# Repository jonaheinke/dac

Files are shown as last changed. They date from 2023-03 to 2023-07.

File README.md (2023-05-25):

# DAC with Headphone Amplifier

## Introduction

## Schematic preview

### Main schematic

main schematic

### Left amplifier (right channel is identical)

left amplifier

### Power supply

power supply

### Front plate

power supply

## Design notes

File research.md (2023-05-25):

TIs Opamps
OPA165x great, probably better
OPA1611 recommended 
https://www.diyaudio.com/community/threads/choosing-of-best-sounding-op-amps-for-the-lowest-possible-thd-n-really-the-best-way.367692/
https://www.ti.com/de-de/amplifier-circuit/op-amps/audio/products.html

https://youtu.be/7irqcglKvKk

https://www.ampslab.com/c300.htm

https://electronics.stackexchange.com/questions/602517/discrete-headphone-amplifier-output-stage

https://www.eevblog.com/forum/projects/who-makes-and-where-to-buy-usb-audio-chips/

https://de.wikipedia.org/wiki/I%C2%B2S
Unbedingt den PCM2706C oder PCM2707C (auf DigiKey nicht verfügbar) von TI nehmen (C ist wichtig, PJT folgt immer, ob R(eel) oder nicht ist egal)
Die anderen (insbesondere PCM290x) haben kein I²S
Unterschied zwischen C und nicht C Chips: https://www.ti.com/lit/an/sbfa019/sbfa019.pdf

andere chips: CM6635 (mouser, wie im schiit hel), CP2615 (24bit 48k discontinued), CS8412, CS8416 (mouser)
Gibt es Alternativen von Cirrus Logic?
http://3.bp.blogspot.com/-GhfnEOvmYFY/UG3X19q91BI/AAAAAAAAAgU/z2ZkhkYbzWM/s1600/i2s_interface.jpg

dac chips:
- PCM1753
- PCM1754
- PCM1755
- PCM1780
- PCM1781
- PCM1782
- CS4344

https://www.headphonesty.com/headphone-power-calculator/

@120dB:
max power: Audeze LCD-3 - 1315mWrms
max voltage: Beyerdynamic DT770 PRO - 12.59Vrms
max current: Audeze LCD-3 - 165.5mArms

@110dB:
max power: Audeze LCD-3 - 132mWrms
max voltage: Beyerdynamic DT770 PRO - 4Vrms
max current: Audeze LCD-3 - 52.4mArms

overcurrent chip:
https://www.digikey.de/de/products/detail/richtek-usa-inc/RT1720GF/6002895
overcurrent circuit: https://forum.allaboutcircuits.com/threads/current-limiting-circuit.170070/  https://electronics.stackexchange.com/questions/200716/current-limiting-with-mosfet

https://hackaday.com/2013/08/27/building-a-high-end-usb-audio-dac/

helpful: caps should be tht (especially dc blocking -> film), for resistors it doesn't matter (except output emitters)
	https://www.youtube.com/watch?v=4ZUBda5oIUo
not so helpful: https://www.youtube.com/watch?v=iJazCWnAmkM

helpful: for dc blocking and even power: use good film cap with large electrolytic in parallel (do they have to be dual polarity for dc block???)
	(0.1-0.2uF for power rails| could this be biased, because no lower value cap was paralleled beforehand?)
	https://www.youtube.com/watch?v=mCk50RTtrT0
	https://www.youtube.com/watch?v=FQOWd-mObFQ

helpful: eevblog multiple caps (especially results at 80% time, multiple can make it worse, check bode plots for all (power) caps)
	https://www.youtube.com/watch?v=BcJ6UdDx1vg

Switchmode? https://www.youtube.com/watch?v=p0fJSaVljeg

good precision current source: https://sound-au.com/ism.htm

TO WATCH/READ:
- https://www.youtube.com/watch?v=PkJqE-EsoWY
- how to design front panels: https://www.youtube.com/watch?v=wg_J9WElvBY

TO BUY:
- case: Hammond 1455N1601BK (02 variant has no separate face plate)
- USB C extender
- isolation heat pads !!!!!!!!!!!!!!!!!! (and check heat sink footprint)
- nylon isolators for screws
- gold screws for panels -> see https://www.youtube.com/watch?v=wg_J9WElvBY @ 5:05
- screw size for 1455N1602BK
  - original: 1455MS100
  - screw length: 9.5mm == 0.375" == 15/32"
  - screw diameter: M3.5 == 3.5mm == 0.138" == 9/64" == #6
  - thread per inch: 32 (e.g #6-32)
- USB to I²S chips
- audio dacs
- output resistors
- output transistors
- vas transistors
- input transistors
- 0 ohm smd resistors
- collection of different smd resistors
- power caps
- film caps for dc blocking and power supply
- ceramic caps (smd?? closest to output transistors, miller compensation)
- button with rgb light for power button and status
- transformer
- FUUULLL BRIDGE RECTIFIAAA!
- power jack

Transformer: 

Mains input: https://www.digikey.de/de/products/detail/delta-electronics/06A2/3830616

USB extender: https://de.aliexpress.com/item/1005003747287943.html oder https://de.aliexpress.com/item/1005003439708042.html

USB breakout: https://www.digikey.de/de/products/detail/sparkfun-electronics/BOB-15100/9770720

function generator: https://www.youtube.com/watch?v=Y1KE8eAC9Bk @ 4:40

use resettable fuse for power supply

diode gates: https://www.sanfoundry.com/analog-electronic-circuits-questions-answers-diode-gates-rectifiers/

https://de.aliexpress.com/item/1005003917089451.html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

https://www.digikey.de/de/products/detail/adafruit-industries-llc/5531/16653412

for silkscreen images: see https://www.youtube.com/watch?v=hoLf8gvvXXU for min line thickness

# other dacs

## schiit LYR

https://www.schiit.com/products/lyr

- has good description of power supply

Gain: 5.7 (15dB) on high, 1.2 (1.35dB) on low

(per channel)
23 Vpeak, 39mApeak @ 600Ω, 450mW
17 Vpeak, 1Apeak @ 16Ω, 9W

## QRV01

https://sjostromaudio.com/pages/index.php/hifi-projects/122-qrv01-headphone-amp
ay yo wtf

- https://jlcpcb.com/help/article/16-How-to-generate-Gerber-and-Drill-files-in-KiCad-6

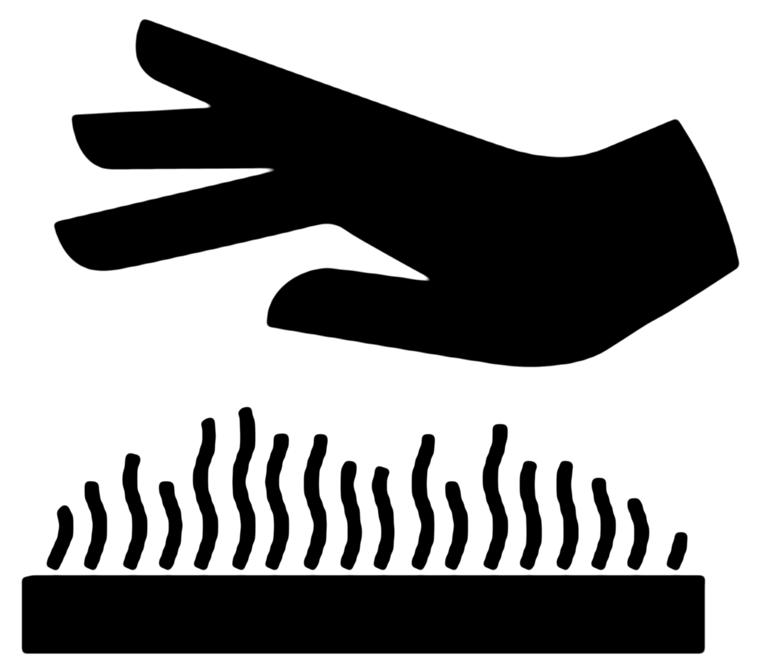
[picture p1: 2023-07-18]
kicad/images/heat-warning.png

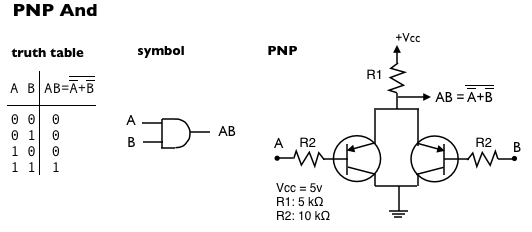
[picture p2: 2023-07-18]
kicad/images/PNP-And.png

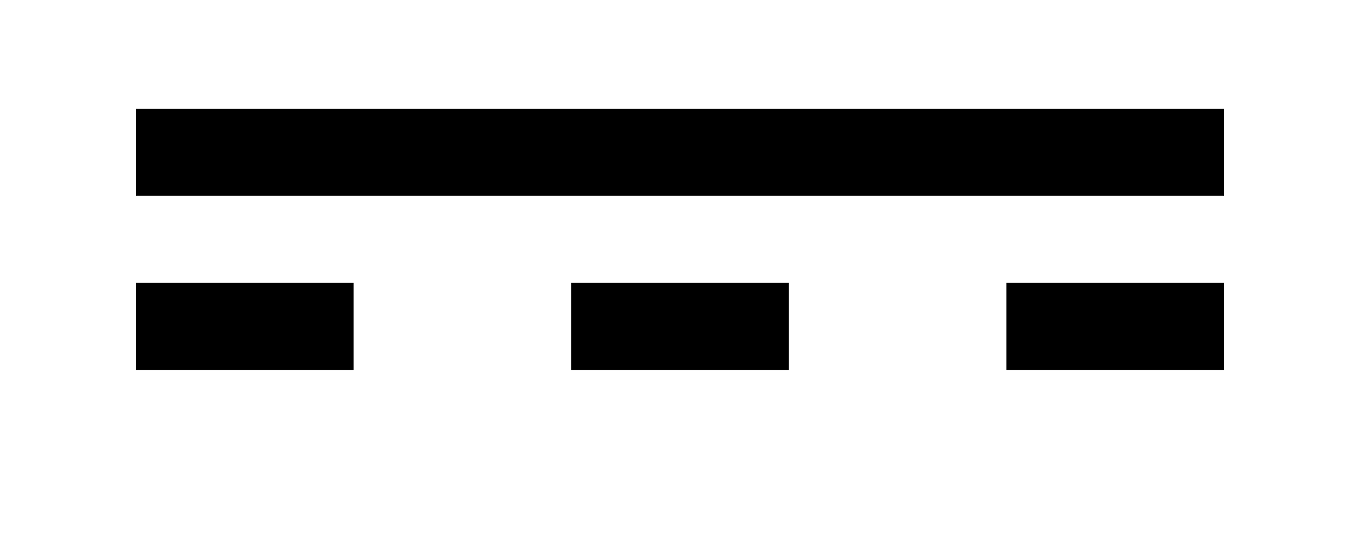
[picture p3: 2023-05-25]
kicad/images/2560px-Direct_current_symbol.svg.png

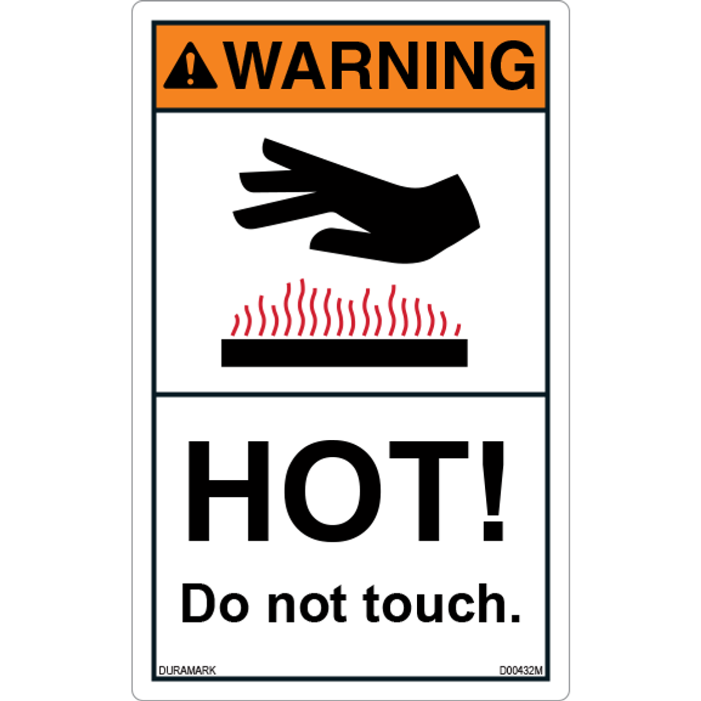
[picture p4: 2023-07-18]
kicad/images/D00432__43247.png

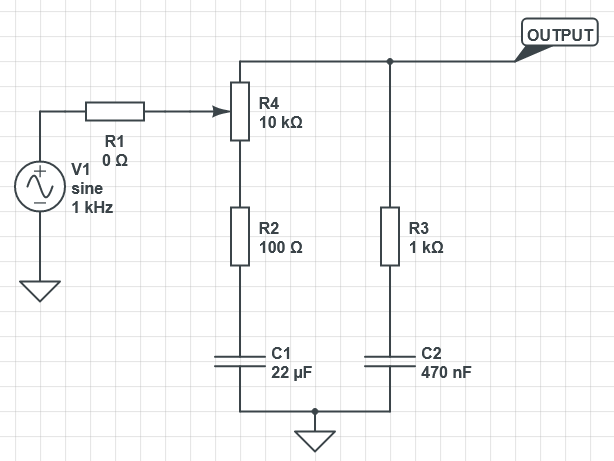
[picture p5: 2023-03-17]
spice/loudness_control_v0.png

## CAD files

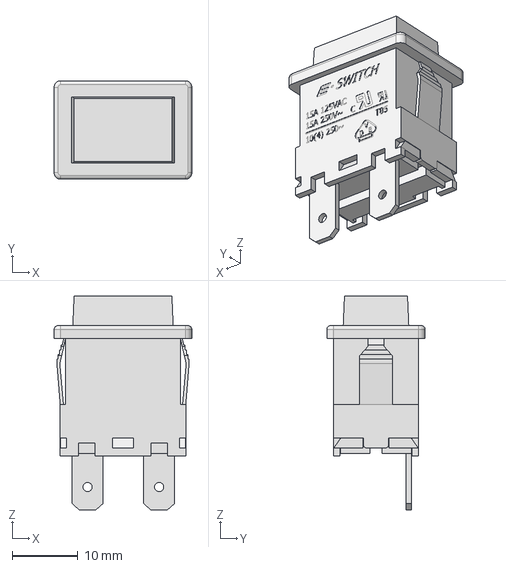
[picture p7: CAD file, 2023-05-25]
kicad/3D/PB1973AxxxxxxEF0.stp
21.0 x 15.0 x 32.6 mm

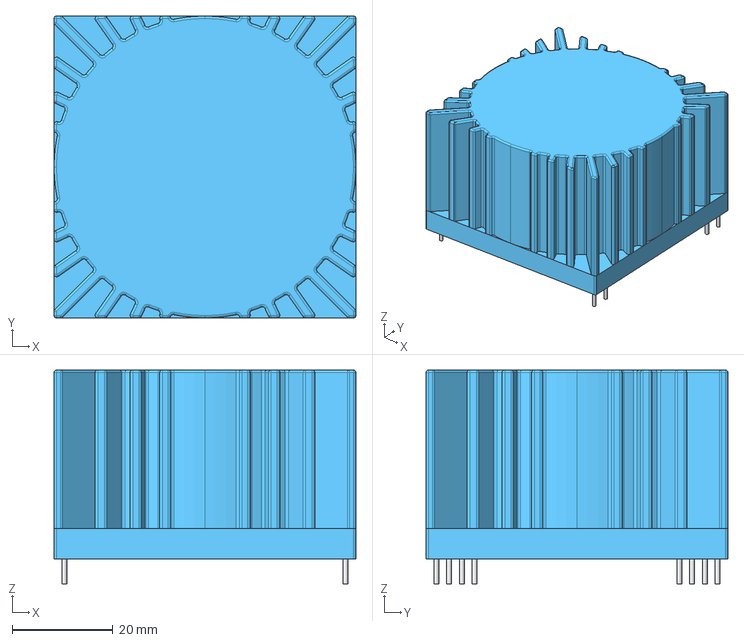
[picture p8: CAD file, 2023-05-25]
kicad/3D/TALEMA_25VA_7006X.step
60.0 x 60.0 x 42.5 mm

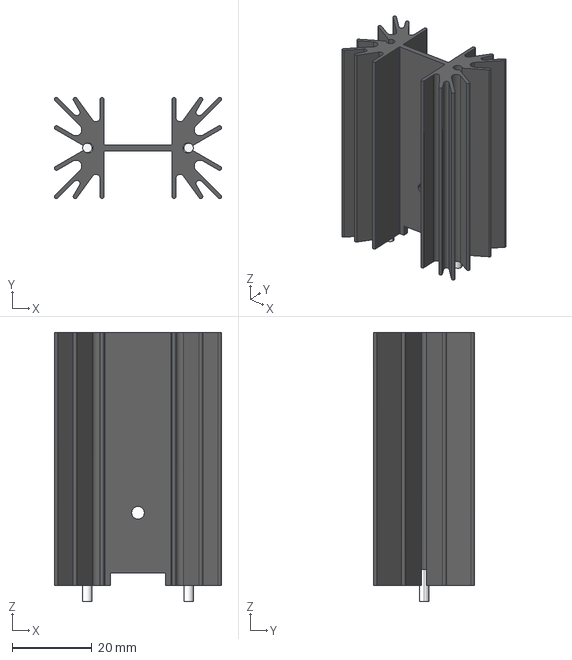
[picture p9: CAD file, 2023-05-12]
kicad/3D/TO-220_Heatsink.stp
41.9 x 25.4 x 67.5 mm

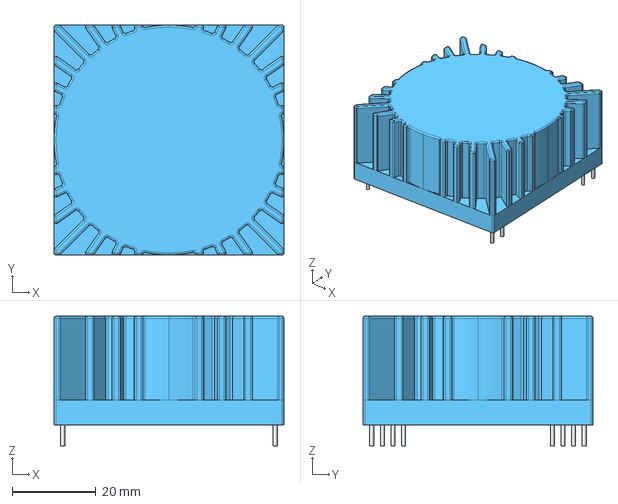
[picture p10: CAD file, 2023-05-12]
kicad/3D/TALEMA_10VA_7004X.step
55.0 x 55.0 x 31.0 mm

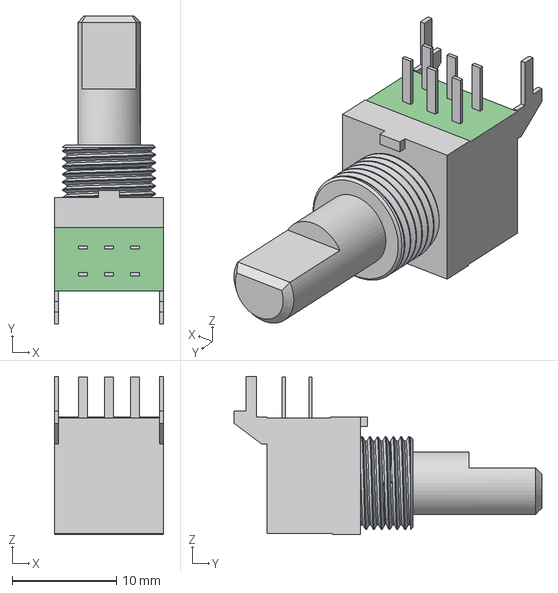
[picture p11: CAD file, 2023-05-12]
kicad/3D/ALPS_RK09L.step
10.5 x 29.6 x 15.2 mm

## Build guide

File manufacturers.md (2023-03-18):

# JLCPCB

- 5pcs 10x10cm 2-layer PCBs for 1,88€ + 3,47€ shipping
- 10pcs 10x10cm 2-layer PCBs for 4,70€ + 7,44€ shipping
- 5pcs 15x10cm 2-layer PCBs for 9,30€ + 6,76€ shipping
- 10pcs 15x10cm 2-layer PCBs for 14,85€ + 8,91€ shipping
- all silkscreen colors available without extra charge

- 4 layer 5pcs 10,2x10,2cm for 6,58€ + 3,47€ shipping

# PCBWAY

- 10pcs 10x10cm 5$ + 6,76$ shipping
- 5pcs 15x10cm 34,54$ + 5,99$ shipping
- all silkscreen colors (except purple and mattes) available without extra charge

# ALLPCB

- 5pcs 10x10cm 2-layer PCBs for 2.50€ + 12€ shipping
- 5pcs 15x10cm 2-layer PCBs for 23€ + 15€ shipping
- non-green silkscreen puts you in the same price bracket as 15x10 (includes matte)

# AISLER

- manufactures in germany

# Pcbcart

- 10x10cm 6€ per board

# Eurocircuits, PCB PROTOTYPE

- viel zu teuer

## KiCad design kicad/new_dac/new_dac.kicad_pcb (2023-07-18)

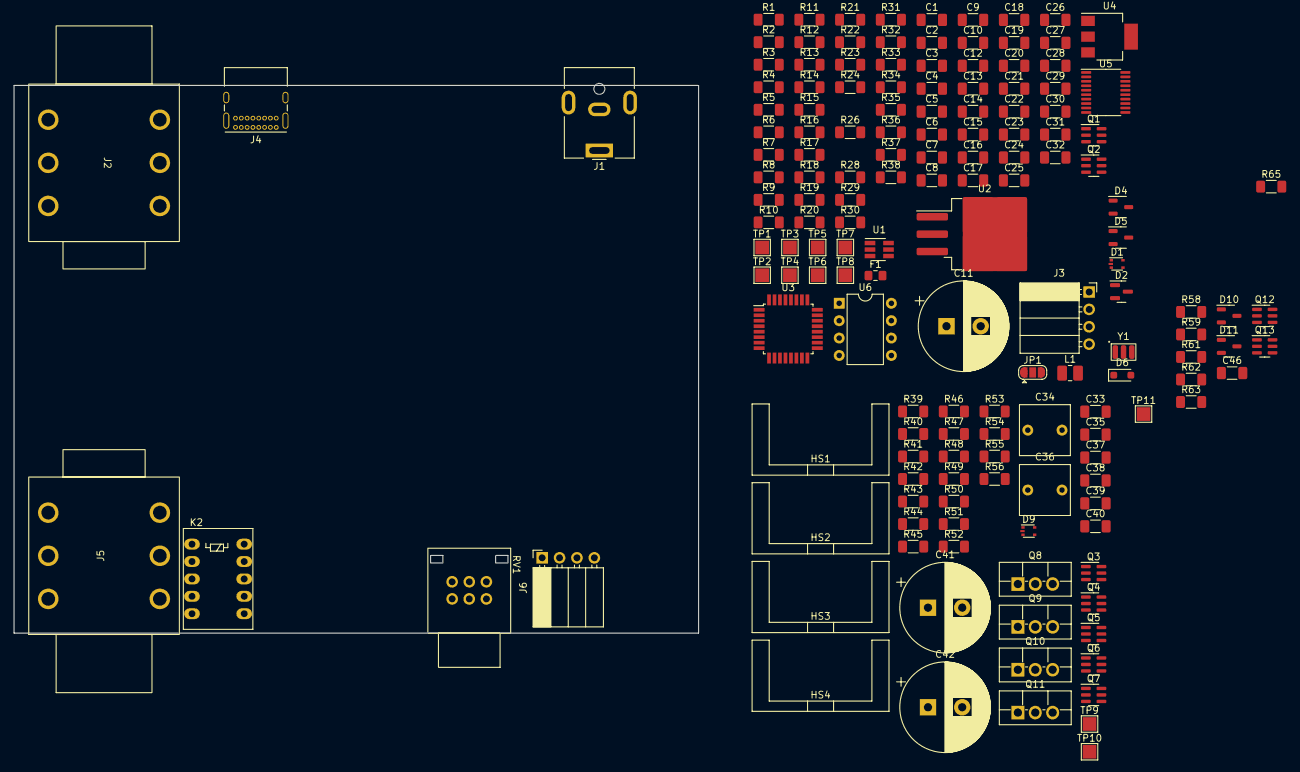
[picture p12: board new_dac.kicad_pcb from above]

Board: 4 copper layers, 100.0 x 80.0 mm, 158 parts (1 on the bottom side), 92 nets, no tracks yet.

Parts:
C1, C7, C9, C10, C14, C15, C18, C21, C32, C37, C38: 100n; C_1206_3216Metric_Pad1.33x1.80mm_HandSolder
C2, C5, C6, C8, C12, C13, C16, C19, C22, C23, C24, C28, C29, C35: 10u; C_1206_3216Metric_Pad1.33x1.80mm_HandSolder
C3, C4, C25, C30, C31: 15n; C_1206_3216Metric_Pad1.33x1.80mm_HandSolder
C11: 470u; CP_Radial_D13.0mm_P5.00mm
C17, C20, C26, C46: 2u2; C_1206_3216Metric_Pad1.33x1.80mm_HandSolder
C27: 1n; C_1206_3216Metric_Pad1.33x1.80mm_HandSolder
C33: 4u7; C_1206_3216Metric_Pad1.33x1.80mm_HandSolder
C34: 4u7; C_Rect_L7.2mm_W7.2mm_P5.00mm_FKS2_FKP2_MKS2_MKP2
C36: 10u; C_Rect_L7.2mm_W7.2mm_P5.00mm_FKS2_FKP2_MKS2_MKP2
C39, C40: 470u; C_1206_3216Metric_Pad1.33x1.80mm_HandSolder
C41, C42: 10u; CP_Radial_D13.0mm_P5.00mm
D1, D9: QUAD_TVS_5V; SOT-665
D2, D7: DUAL_TVS_15V; SOT-23
D4, D5: D; SOT-23-3
D6: D; D_SOD-323_HandSoldering
D10, D11: SOT-23-3
F1: 500mA; Fuse_0805_2012Metric_Pad1.15x1.40mm_HandSolder
HS1, HS2, HS3, HS4: Heatsink; Heatsink_Boyd_507302B00000G
J1: USB_C_Receptacle_USB2.0; BarrelJack_CUI_PJ-063AH_Horizontal
J2: Barrel_Jack_Switch; Audio_Jack_SJ-6307
J3: Conn_01x04; PinSocket_1x04_P2.54mm_Horizontal
J4: USB_C_Receptacle_USB2.0; USB_C_Receptacle_GCT_USB4085
J5: AudioJack3_Switch; Audio_Jack_SJ-6307
J6: AudioJack3_Switch; PinSocket_1x04_P2.54mm_Horizontal
JP1: Ground_Jumper; SolderJumper-3_P1.3mm_Open_RoundedPad1.0x1.5mm
K2: DPDT_Relay; Relay_DPDT_FRT5
L1: 6u8; L_1008_2520Metric_Pad1.43x2.20mm_HandSolder
Q1, Q5, Q6, Q7, Q12: BCM56DS; SC-74-6_1.5x2.9mm_P0.95mm
Q2, Q3, Q4, Q13: BCM53DS; SC-74-6_1.5x2.9mm_P0.95mm
Q8, Q9, Q10, Q11: 2SC4511; TO-220F-3_Vertical
R1, R2: 5k1; R_1206_3216Metric_Pad1.30x1.75mm_HandSolder
R3, R7, R30, R39, R41: 1k5; R_1206_3216Metric_Pad1.30x1.75mm_HandSolder
R4, R5: 22; R_1206_3216Metric_Pad1.30x1.75mm_HandSolder
R6, R10: 430k; R_1206_3216Metric_Pad1.30x1.75mm_HandSolder
R8, R9, R32: 1M; R_1206_3216Metric_Pad1.30x1.75mm_HandSolder
R11: 3k9; R_1206_3216Metric_Pad1.30x1.75mm_HandSolder
R12, R24, R31: 680; R_1206_3216Metric_Pad1.30x1.75mm_HandSolder
R13, R16, R19, R22, R33, R34, R37, R38, R43, R45, R55, R56, R61: 22k; R_1206_3216Metric_Pad1.30x1.75mm_HandSolder
R14, R15, R20, R53, R54, R62: 100k; R_1206_3216Metric_Pad1.30x1.75mm_HandSolder
R17, R18, R26, R51, R52: 15; R_1206_3216Metric_Pad1.30x1.75mm_HandSolder
R21, R44, R46, R63: 10k; R_1206_3216Metric_Pad1.30x1.75mm_HandSolder
R23, R47, R48, R65: 2k2; R_1206_3216Metric_Pad1.30x1.75mm_HandSolder
R28, R29, R49, R50: 8R2; R_1206_3216Metric_Pad1.30x1.75mm_HandSolder
R35, R36, R40, R42: 4k3; R_1206_3216Metric_Pad1.30x1.75mm_HandSolder
R58, R59: 47k; R_1206_3216Metric_Pad1.30x1.75mm_HandSolder
RV1: 10k; RK09L12B
TP1: VBUS; TestPoint_Pad_2.0x2.0mm
TP2: +24; TestPoint_Pad_2.0x2.0mm
TP3: +5V; TestPoint_Pad_2.0x2.0mm
TP4: +22; TestPoint_Pad_2.0x2.0mm
TP5: GND; TestPoint_Pad_2.0x2.0mm
TP6, TP11: +3V3; TestPoint_Pad_2.0x2.0mm
TP7: -3V3; TestPoint_Pad_2.0x2.0mm
TP8: 1V8; TestPoint_Pad_2.0x2.0mm
TP9: VAS_L; TestPoint_Pad_2.0x2.0mm
TP10: VAS_R; TestPoint_Pad_2.0x2.0mm
U1: BD9G101G; SOT-23-6_Handsoldering
U2: LT3088; TO-263-3_TabPin2
U3: PCM2706CPJTR; TQFP-32_7x7mm_P0.8mm
U4: TLV1117LV-33; SOT-223-3_TabPin2
U5: PCM5102A; TSSOP-20_4.4x6.5mm_P0.65mm
U6: LM555xN; DIP-8_W7.62mm
Y1: 12MHz±0.05%; Resonator_Murata

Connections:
+3V3: C7.2, C12.1, C13.1, C14.1, C15.1, C16.1, C21.1, C22.1, R3.2, R7.2, TP6.1, TP11.1, U3.10 (TEST), U3.16 (PSEL), U3.21 (VDD), U3.24 (VBUS), U4.2 (VO), U5.1 (CPVDD), U5.8 (AVDD), U5.20 (DVDD)
+5V: C6.1, C10.1, L1.2, R11.1, R23.1, R33.1, TP3.1, U4.3 (VI), U6.4 (R), U6.8 (VCC)
+20Vreg: C5.1, C11.1, Q3.5 (E1), Q4.5 (E1), Q5.3 (C2), Q6.3 (C2), Q8.2 (C), Q10.2 (C), R13.1, R39.1, R41.1, R47.1, R48.1, TP4.1, U2.2 (OUT)
+24V: C2.1, C26.1, C46.1, J3.1, Q2.5 (E1), Q13.4 (E2), R6.1, R16.1, R20.1, R61.1, R62.1, TP2.1, U1.4 (EN), U1.5 (VCC), U2.3 (IN)
/AMP_L: C39.2, R14.1, R17.1
/AMP_R: C40.2, R15.1, R18.1
/AUDIO_OUT_L: D7.2 (A2), J5.T, K2.8, R28.2
/AUDIO_OUT_R: D7.1 (A1), J5.R, K2.3, R29.2
/BCK: U3.19 (FUNC1), U5.13 (BCK)
/BST: C4.1, U1.1 (BST)
/CAPM: C17.2, U5.4 (CAPM)
/CAPP: C17.1, U5.2 (CAPP)
/CONN_D+: D1.4 (A3), J4.A6 (D+), J4.B6 (D+), R3.1, R5.1
/CONN_D-: D1.3 (A2), J4.A7 (D-), J4.B7 (D-), R4.1
/D+: R5.2, U3.23 (D+)
/D-: R4.2, U3.22 (D-)
/DAC_OUT_L: D9.1 (A1), U5.6 (OUTL)
/DAC_OUT_R: D9.4 (A3), U5.7 (OUTR)
/DATA: U3.17 (DOUT), U5.14 (DIN)
/DC_FUSED: D2.2 (A2), F1.2
/DC_LP_L: C23.1, D4.2 (A), R14.2
/DC_LP_R: C24.1, D5.2 (A), R15.2
/DT: R7.1, U3.15 (DT)
/FEEDBACK: C10.2, R11.2, R12.1, U1.3 (FB)
/LDOO: C18.1, C19.1, TP8.1, U5.18 (LDOO)
/LRCK: U3.5 (FUNC0), U5.15 (LRCK)
/PROT_ARC_L: C28.2, R28.1
/PROT_ARC_R: C29.2, R29.1
/RELAY: K2.1, Q2.6 (C1), R65.1
/RLY_IN_L: C28.1, K2.7, R17.2, R19.2
/RLY_IN_R: C29.1, K2.4, R18.2, R22.2
/Reg_Set: C3.1, R10.1, U2.1 (SET)
/SCK: U3.18 (FUNC2), U5.12 (SCK)
/SSPND: J3.2, U3.11 (~SSPND), U5.17 (XSMT)
/SWITCHING: C4.2, L1.1, U1.6 (LX)
/USB_SHIELD: D1.2 (C), J4.S1 (SHIELD), JP1.3 (B)
/VCCP: C9.2, U3.2 (VCCP)
/VCOM: C8.2, U3.32 (VCOM)
/VNEG: C20.1, TP7.1, U5.5 (VNEG)
/XTI: R8.1, U3.12 (XTI), Y1.1
/XTO: R8.2, U3.13 (XTO), Y1.3
/amplifier/AUDIO_IN_L: D9.3 (A2), RV1.1
/amplifier/AUDIO_IN_R: D9.5 (A4), RV1.4
/amplifier/FB_L: Q5.1 (B1), R35.2, R43.2, R44.1
/amplifier/FB_R: Q6.1 (B1), R36.2, R45.2, R46.1
/amplifier/OPS_L: C39.1, Q8.3 (E), Q9.2 (C), R43.1, R51.1
/amplifier/OPS_R: C40.1, Q10.3 (E), Q11.2 (C), R45.1, R52.1
/amplifier/VAS_L: Q3.3 (C2), Q5.2 (B2), Q5.6 (C1), TP9.1
/amplifier/VAS_R: Q4.3 (C2), Q6.2 (B2), Q6.6 (C1), TP10.1
/old_design/DC_LP_L: C41.1, R53.2, R55.1
/old_design/DC_LP_R: C42.1, R54.2, R56.1
/old_design/DC_NEG: D10.1 (A), D11.1 (A), Q13.1 (B1)
/old_design/DC_POS: D10.3 (K), D11.3 (K), Q12.1 (B1)
/old_design/DC_VD_L: D10.2 (common), R55.2, R58.1
/old_design/DC_VD_R: D11.2 (common), R56.2, R59.1
GND: C2.2, C3.2, C5.2, C6.2, C11.2, C12.2, C35.2, C36.2, C37.2, C38.2, D2.1 (A1), D7.3 (common), D9.2 (C), J3.4, J5.S, J5.SN, JP1.1 (A), Q7.4 (E2), Q7.5 (E1), R6.2, R10.2, R12.2, R13.2, R19.1, R22.1, R37.2, R38.2, R40.2, R42.2, R44.2, R46.2, R49.2, R50.2, RV1.3, RV1.6, TP5.1, U1.2 (GND), U4.1 (GND)
GNDD: C1.2, C7.1, C8.1, C9.1, C13.2, C14.2, C15.2, C16.2, C18.2, C19.2, C20.2, C21.2, C22.2, C23.2, C24.2, C25.2, C27.2, C30.2, C32.2, C41.2, C42.2, D1.5 (A4), D6.2 (A), J4.A1 (GND), J4.A12 (GND), J4.B1 (GND), J4.B12 (GND), JP1.2 (C), K2.2, K2.9, K2.10, Q1.4 (E2), Q1.5 (E1), Q12.4 (E2), Q12.5 (E1), Q13.6 (C1), R1.2, R2.2, R9.1, R31.2, R32.2, R34.2, R58.2, R59.2, U3.1 (PGND), U3.9 (FSEL), U3.20 (DGND), U3.25 (ZGND), U3.26 (AGNDL), U3.31 (AGNDR), U5.3 (CPGND), U5.9 (AGND), U5.10 (DEMP), U5.11 (FLT), U5.16 (FMT), U5.19 (DGND), U6.1 (GND), Y1.2
unnamed: C33.1, RV1.2
unnamed: C33.2, R35.1
unnamed: C34.1, RV1.5
unnamed: C34.2, R36.1
unnamed: C37.1, R51.2
unnamed: C38.1, R52.2
unnamed: D4.1 (K), D5.1 (K), Q1.1 (B1)
unnamed: D6.1 (K), R65.2
unnamed: C32.1, R32.1
unnamed: Q1.2 (B2), Q1.6 (C1), R16.2
unnamed: C26.2, Q1.3 (C2), R21.2
unnamed: Q2.1 (B1), R20.2, R21.1
unnamed: Q3.1 (B1), Q3.4 (E2), R39.2
unnamed: Q3.2 (B2), Q3.6 (C1), R37.1
unnamed: Q4.1 (B1), Q4.4 (E2), R41.2
unnamed: Q4.2 (B2), Q4.6 (C1), R38.1
unnamed: C35.1, Q5.5 (E1), R40.1
unnamed: Q5.4 (E2), Q8.1 (B)
unnamed: C36.1, Q6.5 (E1), R42.1
unnamed: Q7.1 (B1), Q9.3 (E), R49.1
unnamed: Q7.6 (C1), Q9.1 (B), R47.2
unnamed: Q6.4 (E2), Q10.1 (B)
unnamed: Q7.3 (C2), Q11.1 (B), R48.2
unnamed: Q7.2 (B2), Q11.3 (E), R50.1
unnamed: Q12.2 (B2), Q12.6 (C1), Q13.5 (E1), R61.2
unnamed: C46.2, Q12.3 (C2), R63.2
unnamed: Q13.2 (B2), R62.2, R63.1
unnamed: C25.1, U6.5 (CV)
unnamed: R23.2, R24.1, U6.7 (DIS)
unnamed: R26.1, U6.3 (Q)
unnamed: C27.1, R24.2, U6.2 (TR), U6.6 (THR)
unnamed: C30.1, R26.2
unnamed: C31.2, R31.1
unnamed: R33.2, R34.1
VBUS: C1.1, D1.1 (A1), J4.A4 (VBUS), J4.A9 (VBUS), J4.B4 (VBUS), J4.B9 (VBUS), R9.2, TP1.1, U3.3 (HOST)

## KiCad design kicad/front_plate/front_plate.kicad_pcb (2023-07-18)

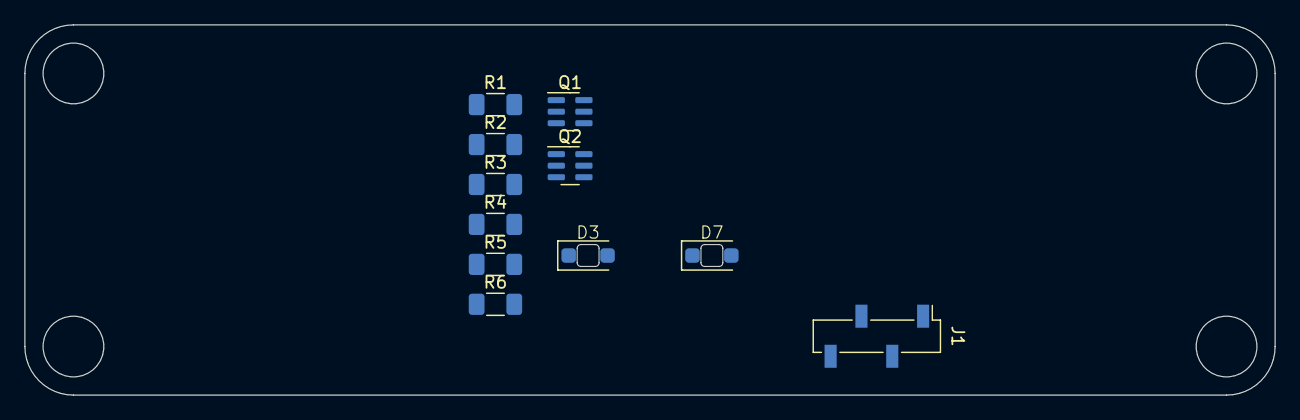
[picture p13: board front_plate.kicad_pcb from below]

Board: 2 copper layers, 103.0 x 30.5 mm, 11 parts (11 on the bottom side), 11 nets, no tracks yet.

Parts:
D3, D7: AMBER; LED_Harvatek_B2601
J1: Conn_01x04; PinSocket_1x04_P2.54mm_Vertical_SMD_Pin1Left
Q1, Q2: BCM56DS; SC-74-6_1.5x2.9mm_P0.95mm
R1: 47k; R_1206_3216Metric_Pad1.30x1.75mm_HandSolder
R2, R4, R5: 2k2; R_1206_3216Metric_Pad1.30x1.75mm_HandSolder
R3: 10k; R_1206_3216Metric_Pad1.30x1.75mm_HandSolder
R6: 4k3; R_1206_3216Metric_Pad1.30x1.75mm_HandSolder

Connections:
+24V: J1.1, R1.2, R3.2, R4.2, R5.2
/ANALOG: J1.3, Q1.1 (B1), R1.1, R2.2
/USB: J1.2, R6.1
GND: J1.4, Q1.4 (E2), Q1.5 (E1), Q2.4 (E2), R2.1
unnamed: D3.2 (A), R4.1
unnamed: D3.1 (K), Q1.3 (C2)
unnamed: D7.2 (A), R5.1
unnamed: D7.1 (K), Q2.6 (C1)
unnamed: Q1.2 (B2), Q1.6 (C1), Q2.2 (B2), R3.1
unnamed: Q2.1 (B1), R6.2
unnamed: Q2.3 (C2), Q2.5 (E1)

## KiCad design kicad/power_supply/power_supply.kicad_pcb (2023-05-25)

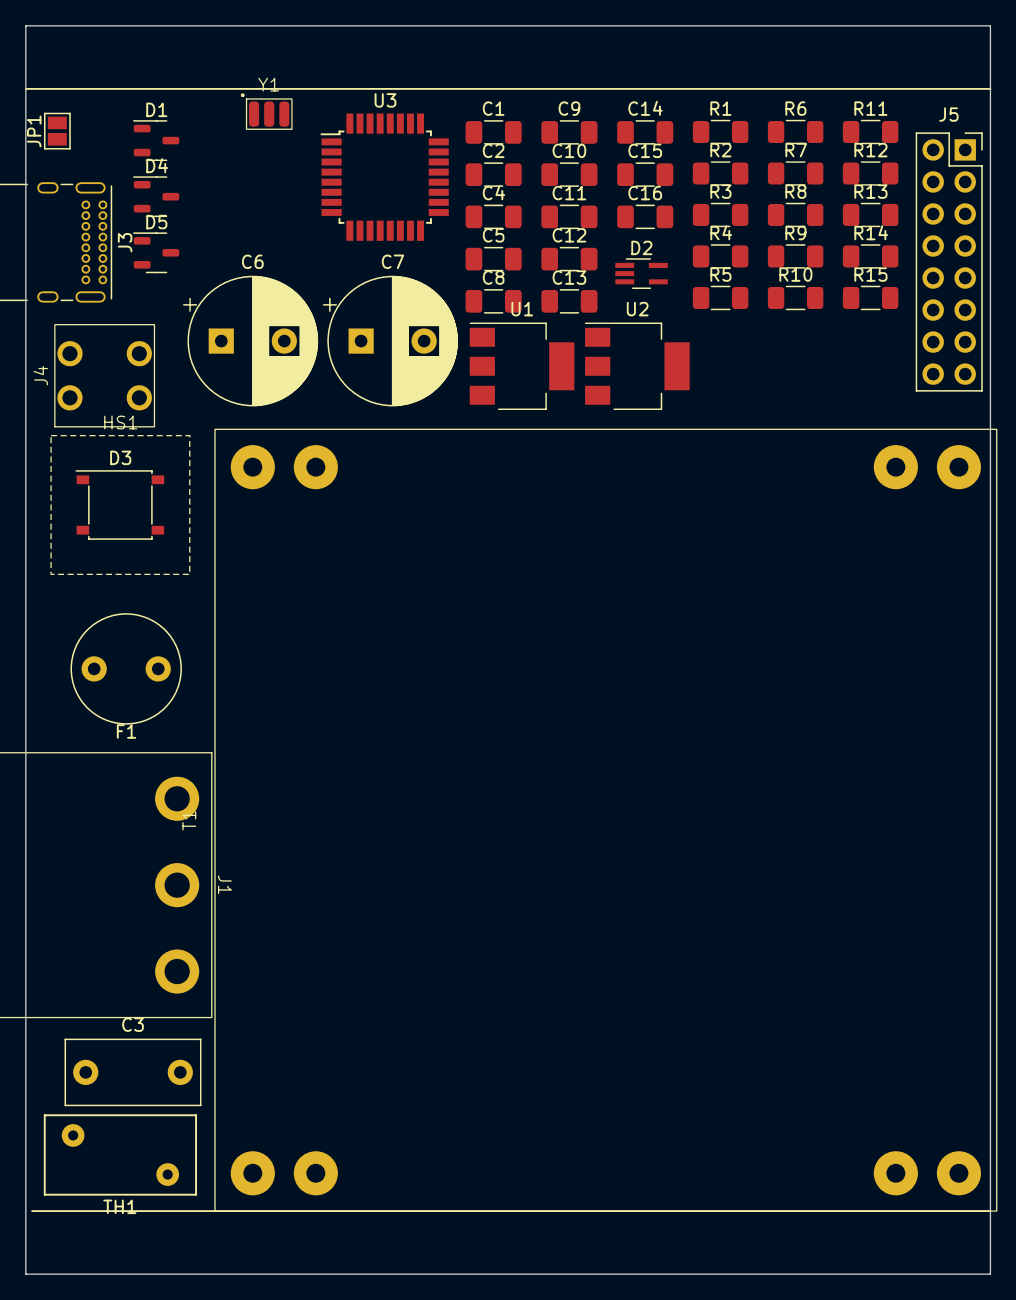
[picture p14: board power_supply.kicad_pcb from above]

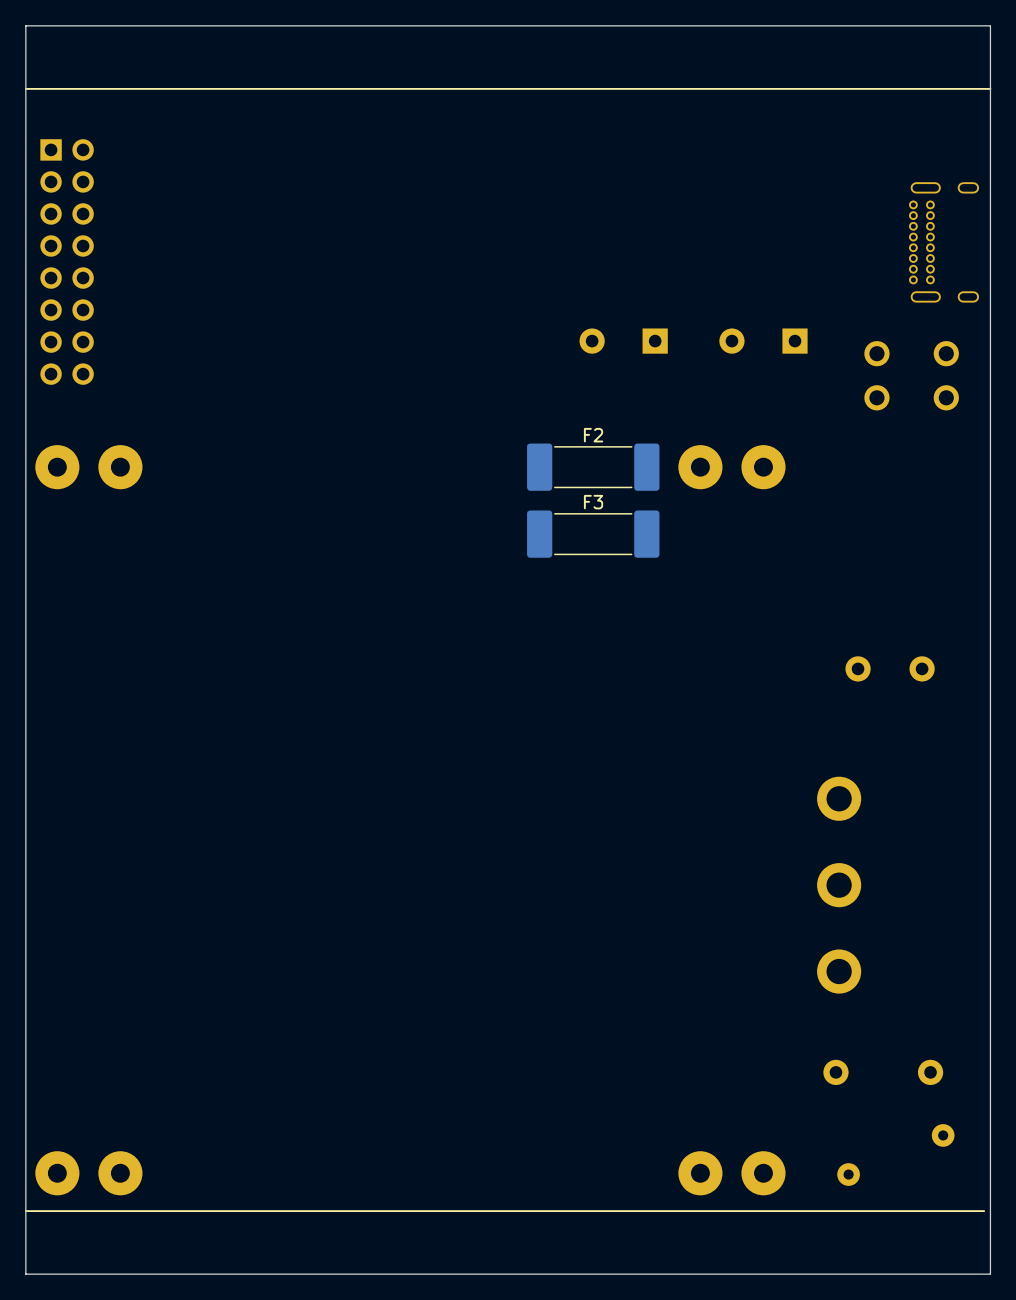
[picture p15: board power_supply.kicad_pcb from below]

Board: 2 copper layers, 76.5 x 99.0 mm, 51 parts (2 on the bottom side), 34 nets, no tracks yet.

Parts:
C1, C4, C8, C10, C13, C14: 100n; C_1206_3216Metric_Pad1.33x1.80mm_HandSolder
C2: 4n7; C_1206_3216Metric_Pad1.33x1.80mm_HandSolder
C3: 3n9; C_Disc_D10.5mm_W5.0mm_P7.50mm
C5: 3u3; C_1206_3216Metric_Pad1.33x1.80mm_HandSolder
C6, C7: 470u; CP_Radial_D10.0mm_P5.00mm
C9, C11, C12, C15, C16: 10u; C_1206_3216Metric_Pad1.33x1.80mm_HandSolder
D1, D4, D5: SOT-23-3
D2: D_TVS_Quadruple; SOT-353_SC-70-5_Handsoldering
D3: Diode_Bridge_Vishay_MBLS
F1: 80mA; Fuse_Littelfuse_372_D8.50mm
F2, F3: 500mA; Fuse_Schurter_UMT250
HS1: Heatsink; Heatsink_10x10
J1: Conn_WallSocket_Earth; WallSocket_Schurter_6160.0003
J3: USB_C_Receptacle_USB2.0; USB_C_Receptacle_GCT_USB4085
J4: Conn_01x02; WAGO_2086-11X2
J5: Conn_02x08_Odd_Even; PinSocket_2x08_P2.54mm_Vertical
JP1: Jumper_2_Open; SolderJumper-2_P1.3mm_Open_Pad1.0x1.5mm
R1, R6, R7: 22; R_1206_3216Metric_Pad1.30x1.75mm_HandSolder
R2: 33k; R_1206_3216Metric_Pad1.30x1.75mm_HandSolder
R3, R4: 5k1; R_1206_3216Metric_Pad1.30x1.75mm_HandSolder
R5, R8: 1k5; R_1206_3216Metric_Pad1.30x1.75mm_HandSolder
R9, R10: 10k; R_1206_3216Metric_Pad1.30x1.75mm_HandSolder
R11: 1M; R_1206_3216Metric_Pad1.30x1.75mm_HandSolder
R12, R15: 100; R_1206_3216Metric_Pad1.30x1.75mm_HandSolder
R13, R14: 1k1; R_1206_3216Metric_Pad1.30x1.75mm_HandSolder
T1: 70063K; Talema_Transformer_2P2S_25VA
TH1: MOV; RV_Disc_D12mm_W6.3mm_P7.5mm
U1: LM317_SOT-223; SOT-223-3_TabPin2
U2: LM337_SOT223; SOT-223-3_TabPin2
U3: PCM2706CPJTR; TQFP-32_7x7mm_P0.8mm
Y1: 12MHz±0.05%; Resonator_Murata

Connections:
+3V3: C8.2, R5.2, R8.2, U3.10 (TEST), U3.16 (PSEL), U3.21 (VDD)
+20Vreg: C13.1, C15.1, D4.2 (common), J5.1, R12.1, U1.2 (VO)
+25V: C6.1, D4.3 (K), F2.2, J5.2, R9.1, U1.3 (VI)
-20Vreg: C14.2, C16.2, D5.2 (common), J5.5, R15.2, U2.3 (VO)
-25V: C7.2, D5.1 (A), F3.2, J5.6, R10.2, U2.2 (VI)
/BCK: J5.15, U3.19 (FUNC1)
/CONN_D+: D2.4 (A3), J3.A6 (D+), J3.B6 (D+), R5.1, R7.1
/CONN_D-: D2.3 (A2), J3.A7 (D-), J3.B7 (D-), R6.1
/D+: R7.2, U3.23 (D+)
/D-: R6.2, U3.22 (D-)
/DATA: J5.10, U3.17 (DOUT)
/DT: R8.1, U3.15 (DT)
/LIVE: J4.2, T1.1
/LRCK: J5.16, U3.5 (FUNC0)
/NEUTRAL: C3.2, J1.2 (AC_N), TH1.2
/SCK: J5.14, U3.18 (FUNC2)
/SSPND: J5.11, U3.11 (~SSPND)
/VCOM: C9.2, U3.32 (VCOM)
/V_{rect}+: D3.1 (+), F2.1
/V_{rect}-: D3.3 (-), F3.1
/XTI: R11.1, U3.12 (XTI), Y1.1
/XTO: R11.2, U3.13 (XTO), Y1.3
GND: C1.1, C6.2, C7.1, C11.2, C12.1, C13.2, C14.1, C15.2, C16.1, D1.2 (A), J5.3, J5.4, J5.12, J5.13, R1.2, R9.2, R10.1, R13.2, R14.1
GNDD: C2.2, C4.1, C5.1, C8.1, C9.1, C10.1, D2.5 (A4), J3.A1 (GND), J3.A12 (GND), J3.B1 (GND), J3.B12 (GND), JP1.1 (A), R2.1, R3.2, R4.2, U3.1 (PGND), U3.3 (HOST), U3.9 (FSEL), U3.20 (DGND), U3.25 (ZGND), Y1.2
unnamed: C2.1, D2.2 (C), J3.S1 (SHIELD), JP1.2 (B), R2.2
unnamed: C11.1, D4.1 (A), R12.2, R13.1, U1.1 (ADJ)
unnamed: C12.2, D5.3 (K), R14.2, R15.1, U2.1 (ADJ)
unnamed: F1.1, J1.1 (AC_P)
unnamed: C1.2, D1.1 (K), D1.3 (K), J1.3 (EARTH), R1.1
unnamed: J3.A5 (CC1), R3.1
unnamed: J3.B5 (CC2), R4.1
unnamed: C3.1, F1.2, J4.1, TH1.1
unnamed: C10.2, U3.2 (VCCP)
VBUS: C4.2, C5.2, D2.1 (A1), J3.A4 (VBUS), J3.A9 (VBUS), J3.B4 (VBUS), J3.B9 (VBUS), J5.9, U3.24 (VBUS)

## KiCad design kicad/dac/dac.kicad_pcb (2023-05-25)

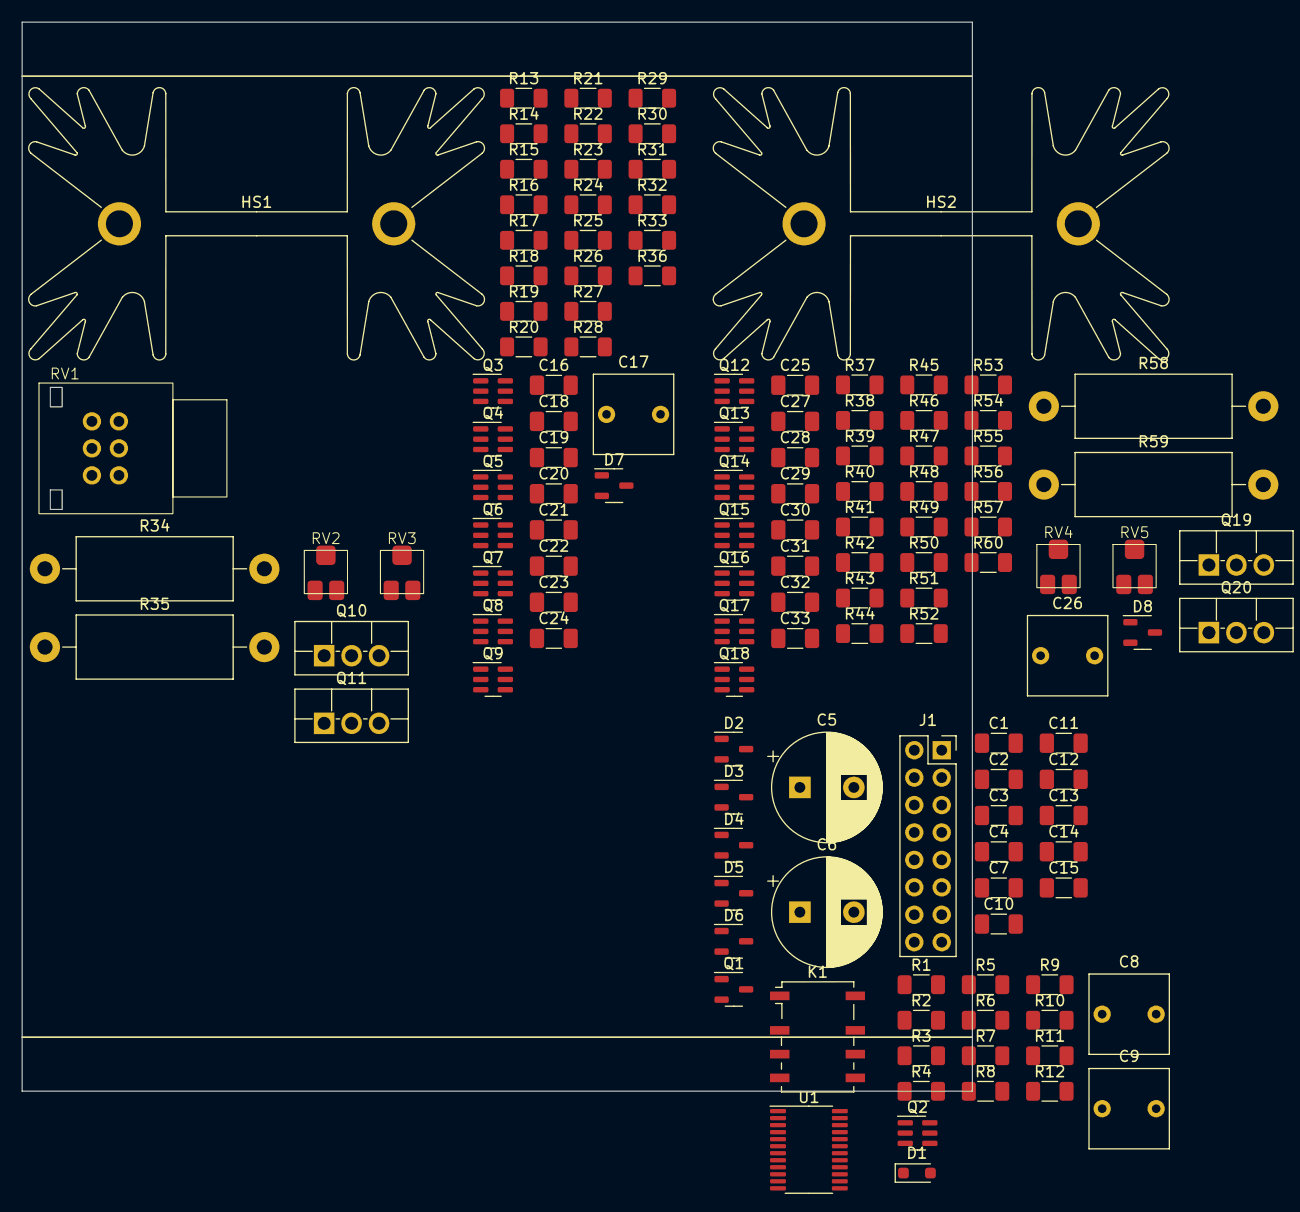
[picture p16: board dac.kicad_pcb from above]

Board: 4 copper layers, 88.0 x 99.0 mm, 131 parts (0 on the bottom side), 89 nets, no tracks yet.

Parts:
C1, C2, C4, C11, C12, C13, C14, C15, C18, C19, C21, C22, C23, C27, C28, C30, C31, C32: 10u; C_1206_3216Metric_Pad1.33x1.80mm_HandSolder
C3, C10: 100n; C_1206_3216Metric_Pad1.33x1.80mm_HandSolder
C5, C6: 470u; CP_Radial_D10.0mm_P5.00mm
C7: 3u3; C_1206_3216Metric_Pad1.33x1.80mm_HandSolder
C8, C9, C17, C26: 3u3; C_Rect_L7.2mm_W7.2mm_P5.00mm_FKS2_FKP2_MKS2_MKP2
C16, C24, C25, C33: 20n; C_1206_3216Metric_Pad1.33x1.80mm_HandSolder
C20, C29: 30p; C_1206_3216Metric_Pad1.33x1.80mm_HandSolder
D1: D; D_SOD-323_HandSoldering
D2, D3, D4, D5, D6, D7, D8: SOT-23-3
HS1, HS2: Heatsink; Heatsink_Fischer_SK129-STS_42x25mm_2xDrill2.5mm
J1: Conn_02x08_Odd_Even; PinSocket_2x08_P2.54mm_Vertical
K1: Relay; Relay_DPDT_Omron_G6K-2F-Y
Q1: MMBT5551; SOT-23-3
Q2, Q3, Q4, Q7, Q9, Q12, Q13, Q16, Q18: BCM53DS; SC-74-6_1.5x2.9mm_P0.95mm
Q5, Q6, Q8, Q14, Q15, Q17: BCM56DS; SC-74-6_1.5x2.9mm_P0.95mm
Q10, Q19: 2SC4511; TO-220F-3_Vertical
Q11, Q20: 2SA1725; TO-220F-3_Vertical
R1: 47k; R_1206_3216Metric_Pad1.30x1.75mm_HandSolder
R2, R3, R11, R12: 10k; R_1206_3216Metric_Pad1.30x1.75mm_HandSolder
R4, R5, R10: 100k; R_1206_3216Metric_Pad1.30x1.75mm_HandSolder
R6, R7, R36, R60: 16; R_1206_3216Metric_Pad1.30x1.75mm_HandSolder
R8, R9: 2; R_1206_3216Metric_Pad1.30x1.75mm_HandSolder
R13, R18, R20, R29, R37, R42, R44, R53: 68; R_1206_3216Metric_Pad1.30x1.75mm_HandSolder
R14, R15, R24, R26, R38, R39, R48, R50: 27k; R_1206_3216Metric_Pad1.30x1.75mm_HandSolder
R16, R17, R21, R22, R28, R40, R41, R45, R46, R52: 430; R_1206_3216Metric_Pad1.30x1.75mm_HandSolder
R19, R43: 680; R_1206_3216Metric_Pad1.30x1.75mm_HandSolder
R23, R25, R27, R47, R49, R51: 2k2; R_1206_3216Metric_Pad1.30x1.75mm_HandSolder
R30, R54: 12; R_1206_3216Metric_Pad1.30x1.75mm_HandSolder
R31, R55: 22; R_1206_3216Metric_Pad1.30x1.75mm_HandSolder
R32, R33, R56, R57: 33; R_1206_3216Metric_Pad1.30x1.75mm_HandSolder
R34, R35, R58, R59: 2; R_Axial_DIN0614_L14.3mm_D5.7mm_P20.32mm_Horizontal
RV1: 10k; RK09L12B
RV2, RV4: 100; TC33
RV3, RV5: 500; TC33
U1: CS4349; TSSOP-24_4.4x7.8mm_P0.65mm

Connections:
+20Vreg: C19.1, C22.1, C28.1, C31.1, J1.1, Q4.5 (E), Q7.5 (E), Q13.5 (E), Q16.5 (E), R19.2, R29.2, R43.2, R53.2
+25V: C5.1, C8.2, D5.3 (K), D6.3 (K), J1.2, Q8.3 (C), Q10.2 (C), Q17.3 (C), Q19.2 (C)
-20Vreg: C18.1, C21.1, C27.1, C30.1, J1.5, R16.1, R22.1, R25.1, R31.1, R40.1, R46.1, R49.1, R55.1
-25V: C6.2, C9.1, D5.1 (A), D6.1 (A), J1.6, Q9.2 (B), Q9.3 (C), Q9.4 (E), Q9.6 (C), Q11.2 (C), Q18.2 (B), Q18.3 (C), Q18.4 (E), Q18.6 (C), Q20.2 (C)
/AMP_L: C12.1, D7.2 (common), K1.8, R2.2, R24.2, R32.1, R33.2, R34.2, R35.1, R36.2
/AMP_R: C13.1, D8.2 (common), K1.5, R3.2, R48.2, R56.1, R57.2, R58.2, R59.1, R60.2
/DAC_L: R13.1, U1.15 (AOUTA)
/DAC_R: R37.1, U1.22 (AOUTB)
/DATA: J1.10, U1.11 (SDIN)
/DC_LP_L: C14.1, D2.2 (common), R4.2
/DC_LP_R: C15.1, D3.2 (common), R5.2
/LRCK: J1.16, U1.12 (LRCK)
/OUT_L: D6.2 (common), R4.1, R8.2
/OUT_R: D5.2 (common), K1.4, R5.1, R9.2
/POPGUARD: R1.2, U1.8 (POPGUARD/TSTO)
/PROT_ARC_L: C12.2, R8.1
/PROT_ARC_R: C13.2, R9.1
/RLY+: D1.1 (K), K1.1
/RLY_NC_R: K1.3, R7.2
/SCK: J1.14, U1.10 (SCLK)
/VBIAS: C4.2, U1.17 (VBIAS)
/VD_FILT: C10.1, C11.1, U1.6 (VD_FILT)
/VQ: C7.1, U1.20 (VQ)
/amplifier_left/CC_IPS_L: Q4.3 (C), R18.2, R20.2, RV2.2
/amplifier_left/CC_VAS_L: Q7.3 (C), R27.2, R30.1
/amplifier_left/CM_L: Q3.3 (C), Q5.1 (B), Q5.2 (B), Q5.3 (C)
/amplifier_left/FB_L: Q3.2 (B), R23.2, R24.1
/amplifier_left/INPUT_L: Q3.1 (B), R14.2, RV1.2
/amplifier_left/IPS_L: C20.1, Q3.6 (C), Q5.6 (C), Q6.1 (B)
/amplifier_left/VAS_DARL_L: Q6.2 (B), Q6.5 (E), R25.2
/amplifier_left/V_{OPS}+_L: Q8.4 (E), Q10.1 (B), R32.2
/amplifier_left/V_{OPS}-_L: Q9.5 (E), Q11.1 (B), R33.1
/amplifier_left/V_{bias}+_L: C23.1, D7.3 (K), Q8.2 (B), Q8.6 (C), R30.2
/amplifier_left/V_{bias}-_L: C20.2, C23.2, D7.1 (A), Q6.3 (C), Q8.5 (E), Q9.1 (B), RV3.2, RV3.3
/amplifier_left/V_{bias}B_L: Q8.1 (B), R27.1, R28.2
/amplifier_left/V_{q}+_L: Q10.3 (E), R34.1
/amplifier_left/V_{q}-_L: Q11.3 (E), R35.2
/amplifier_left/ZOBEL_L: C24.2, R36.1
/amplifier_right/CC_IPS_R: Q13.3 (C), R42.2, R44.2, RV4.2
/amplifier_right/CC_VAS_R: Q16.3 (C), R51.2, R54.1
/amplifier_right/CM_R: Q12.3 (C), Q14.1 (B), Q14.2 (B), Q14.3 (C)
/amplifier_right/FB_L: Q12.2 (B), R47.2, R48.1
/amplifier_right/INPUT_R: Q12.1 (B), R38.2, RV1.5
/amplifier_right/IPS_R: C29.1, Q12.6 (C), Q14.6 (C), Q15.1 (B)
/amplifier_right/VAS_DARL_R: Q15.2 (B), Q15.5 (E), R49.2
/amplifier_right/V_{OPS}+_R: Q17.4 (E), Q19.1 (B), R56.2
/amplifier_right/V_{OPS}-_R: Q18.5 (E), Q20.1 (B), R57.1
/amplifier_right/V_{bias}+_R: C32.1, D8.3 (K), Q17.2 (B), Q17.6 (C), R54.2
/amplifier_right/V_{bias}-_R: C29.2, C32.2, D8.1 (A), Q15.3 (C), Q17.5 (E), Q18.1 (B), RV5.2, RV5.3
/amplifier_right/V_{bias}B_R: Q17.1 (B), R51.1, R52.2
/amplifier_right/V_{q}+_R: Q19.3 (E), R58.1
/amplifier_right/V_{q}-_R: Q20.3 (E), R59.2
/amplifier_right/ZOBEL_R: C33.2, R60.1
GND: C1.2, C2.2, C3.2, C5.2, C6.1, C7.2, C8.1, C9.2, C10.2, C11.2, C14.2, C15.2, C16.1, C18.2, C19.2, C21.2, C22.2, C24.1, C25.1, C27.2, C28.2, C30.2, C31.2, C33.1, D4.2 (common), J1.3, J1.4, J1.12, J1.13, Q6.6 (C), Q15.6 (C), R2.1, R3.1, R6.1, R7.1, R14.1, R15.1, R23.1, R26.1, R38.1, R39.1, R47.1, R50.1, RV1.3, RV1.6, U1.1 (DIF2/AD1/CDOUT), U1.2 (DEM/AD0/~CS), U1.4 (DIF1/SCL/CCLK), U1.7 (GND), U1.19 (GND)
unnamed: C16.2, C17.1, R13.2
unnamed: C17.2, RV1.1
unnamed: C25.2, C26.1, R37.2
unnamed: C26.2, RV1.4
unnamed: D2.1 (A), D3.1 (A), D4.1 (A), Q2.2 (B)
unnamed: D2.3 (K), D3.3 (K), D4.3 (K), Q1.1 (B)
unnamed: Q1.3 (C), R11.2
unnamed: Q1.2 (E), Q2.3 (C)
unnamed: Q2.1 (B), R10.2, R11.1
unnamed: Q2.4 (E), R12.1
unnamed: Q3.5 (E), R17.1
unnamed: Q3.4 (E), R21.2
unnamed: Q4.1 (B), Q4.4 (E), R19.1
unnamed: Q4.2 (B), Q4.6 (C), R15.2
unnamed: Q5.5 (E), R16.2
unnamed: Q5.4 (E), R22.2
unnamed: Q6.4 (E), R31.2
unnamed: Q7.1 (B), Q7.4 (E), R29.1
unnamed: Q7.2 (B), Q7.6 (C), R26.2
unnamed: Q12.5 (E), R41.1
unnamed: Q12.4 (E), R45.2
unnamed: Q13.1 (B), Q13.4 (E), R43.1
unnamed: Q13.2 (B), Q13.6 (C), R39.2
unnamed: Q14.5 (E), R40.2
unnamed: Q14.4 (E), R46.2
unnamed: Q15.4 (E), R55.2
unnamed: Q16.1 (B), Q16.4 (E), R53.1
unnamed: Q16.2 (B), Q16.6 (C), R50.2
unnamed: R17.2, R18.1, RV2.1
unnamed: R20.1, R21.1, RV2.3
unnamed: R28.1, RV3.1
unnamed: R41.2, R42.1, RV4.1
unnamed: R44.1, R45.1, RV4.3
unnamed: R52.1, RV5.1
VBUS: C1.1, C2.1, C3.1, C4.1, J1.9, R1.1, U1.3 (DIF0/SDA/CDIN), U1.5 (VLC), U1.9 (VLS), U1.18 (VA)

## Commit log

2023-03-18 added PCB manufacturer evaluation added temporary first schematic design
    [dac.kicad_pcb, dac.kicad_sch]
2023-03-19 added mono amplifier and tvs diodes
    [dac.kicad_sch]
2023-03-26 split power supply to different board
    [amplifier_left.kicad_sch, amplifier_right.kicad_sch, dac.kicad_pcb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]
2023-05-12 completed power supply footprints and placement
    [ALPS_RK09L.step, Raspberry_PI_Heatsink.step, TALEMA_10VA_7004X.step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]

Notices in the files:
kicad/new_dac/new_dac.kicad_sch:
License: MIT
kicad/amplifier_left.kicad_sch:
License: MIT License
